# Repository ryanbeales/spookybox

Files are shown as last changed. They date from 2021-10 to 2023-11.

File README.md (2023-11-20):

# What is this?
It's a spooky box version 3! For 2023 it's no longer in a pumpkin, but back in it's box. Version 1 was in a box and that's how it got it's name and we're back to continuing the tradition. You can check out what the 2021 version did [here](https://github.com/ryanbeales/spookybox/tree/spookyboxv1) and 2023 [here](https://github.com/ryanbeales/spookybox/tree/spookyboxv2).

This is some face tracking which is then used as an input to drive some servos that direct some fake plastic eyeballs to follow people around. All this to hopefully spook our Halloween vistors. Success rate so far is about 10% of kids spooked in both 2021 and 2022. 2023 upped this to a better 30%. 2024 really needs to terrify people...

Here's a video of it working (click on the image to play it):
<br>SpookyboxV3 outside (http://www.youtube.com/watch?<br>v=ynq5hFvTToc)<br>

For 2023 it was mostly UI improvementsm so here's a video of the UI:
<br>SpookyboxV3 inside (http://www.youtube.com/watch?v=F0AnC8ocOAw)<br>

The red dot will aim where it finds a face. Posenet is pretty good at finding faces, what is not good is me trying to make a single point out of that. It should be finding the top left corner of the bounding box of the face it finds. It's not quite doing that. But better than nothing! For 2023 i've added some manual controls and some tuning for the lid servo open/close points so we can get that satisfying slap when it closes. There's a manual lid control option which will keep the eyes tracking whatever it finds.

# What's going on here?

Spookyboxv1 used OpenCV running on the Raspberry Pi 3, however, this was way to underpowered for what I was attempting to do. 
Spookyboxv2 offloaded all the face detecting to a desktop or phone browser with an attached GPU or AI accelleration (in a phone) and can find faces/ears/noses/eyes MUCH faster and more accurately with Tensorflow JS and PoseNet.
Spookyboxv3 much the same as v2, but software improvements and back to the box.

Maybe this diagram might help? Maybe it just makes things more confusing.

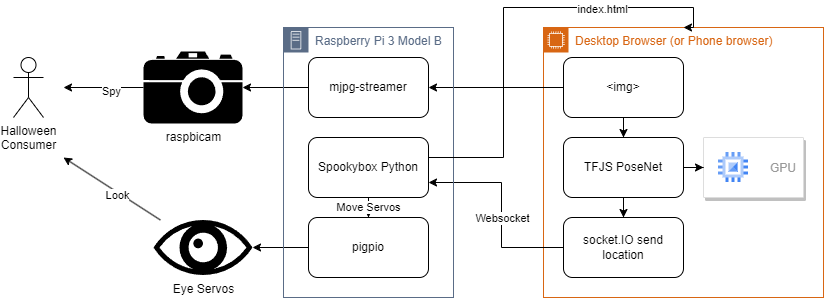
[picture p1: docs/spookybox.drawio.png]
diagram


# Parts needed/used

- Monkmakes Servosix
- 3 Servos
- Bits'o'wire
- Random amazon plastic eyes
- 1 metal rod
- Glue
- 3D print of ./freecad_models/Spookybox2023-2.FCStd (designed to fit everything below)
- 3D print of ./freecad_models/ServoSixCase.FCStd
- 3D print of [Raspberry Pi 3 Model A+ Case](http://www.thingiverse.com/thing:3683365)
- 3D print of [Raspberry pi camera case/enclosure](https://www.thingiverse.com/thing:92208)
- 3D print of [Dasaki Compact Animatronic Eyes](https://www.thingiverse.com/thing:266765)
- A box
- Some small screws for the animatronic eyes
- Raspberry Pi 3 Model A+
- Raspbicam
- SD Card
- Power supply
- Some more powerful hardware to drive it (a semi-recent phone will do, or a Nvidia 4090)

# Assembly photos

A view of the outside:
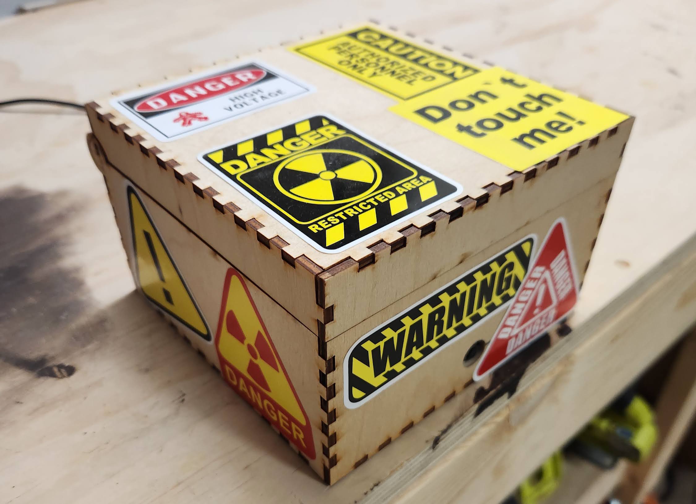
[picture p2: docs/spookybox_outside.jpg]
Outside
</br></br>

And the inside:
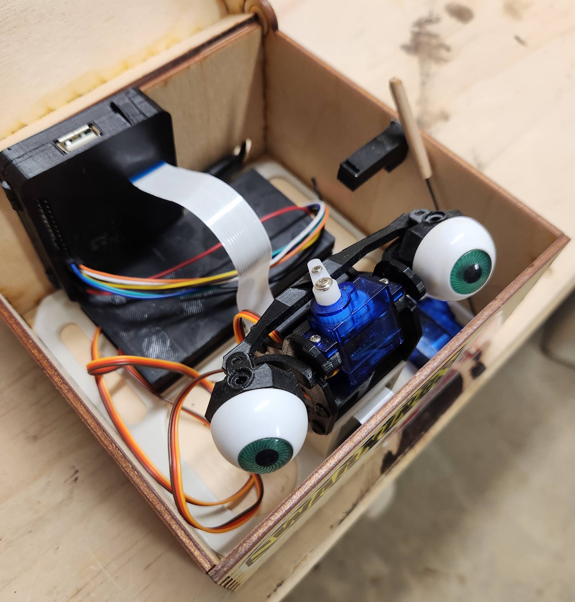
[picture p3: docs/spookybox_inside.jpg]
Inside
</br></br>

The raspbicam has a little hole to peek through the box, harder to see with all the stickers. The lid servo is using a small metal rod with a dowel on the end to make better contact with an old 3D printed part that is glued to the lid.

# Running it
These are my rough notes so I remember what to do for Halloween 2024.

1. Get a raspberry pi and camera module, and servos
1. 3D print all the parts
1. Git clone this in to /home/pi/src/
1. Run install.sh
1. Get spooky.
1. Open a browser on a mobile or desktop device to http://spookyboxpi.local:5000/static/index.html

# TODO

- Increased spookyness (Speakers and some AI voice cloning? Smoke machine?)
- Some sort of CI/CD to pull new changes of the UI down (that's taking my day job home...)
- Add more power. Sometimes the lid servo can consume all the power so the eyes get stuck.

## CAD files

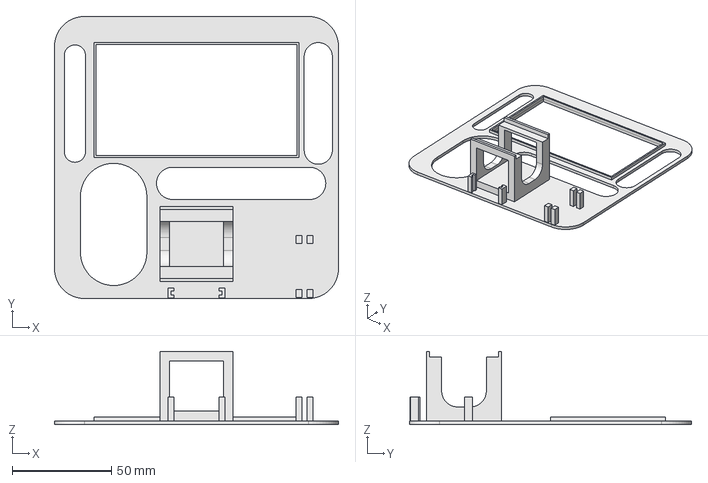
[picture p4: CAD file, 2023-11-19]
freecad_model/SpookyBox2023-2.FCStd
143.0 x 142.0 x 37.0 mm

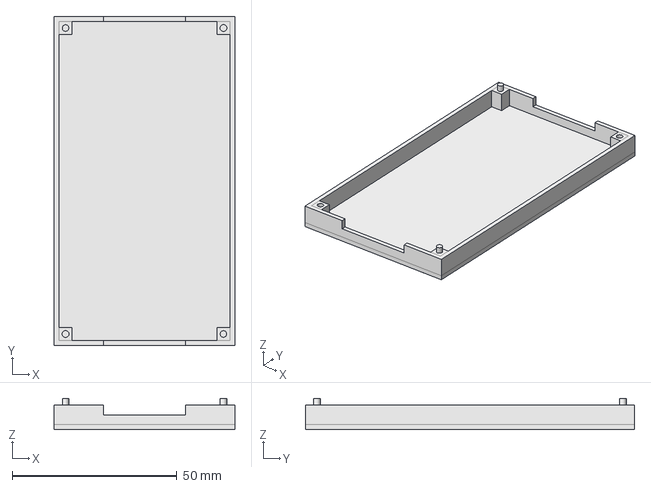
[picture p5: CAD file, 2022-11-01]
freecad_model/ServoSixCase.FCStd
55.0 x 100.0 x 9.50 mm

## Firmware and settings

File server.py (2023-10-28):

from flask import Flask, render_template, current_app
from flask_socketio import SocketIO
from servos import Servo

app = Flask(__name__)
app.config['SECRET_KEY'] = 'spooooooky'
socketio = SocketIO(app)

# Set up our servos, offset by -20 to account for where it was installed
horizontalservo = Servo(23, offset=-20)
verticalservo = Servo(27)
lidservo = Servo(17)

@socketio.on('faceposition')
def handle_message(data):
    #message format is [current x, current y, max x, max y, lidposition].
    current_X = data[0]
    current_Y = data[1]
    lidposition = data[2]

    # Move eyes
    horizontalservo.set_fraction(current_X, minimum=-36, maximum=30)
    verticalservo.set_fraction(current_Y, minimum=-45, maximum=45)
    # Open=-60, closed=20
    lidservo.set_fraction(lidposition, minimum=-60, maximum=20)

if __name__ == '__main__':
    # Bind to all addresses, allow to start via systemd
    socketio.run(app, host='0.0.0.0', allow_unsafe_werkzeug=True)

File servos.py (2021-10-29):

import pigpio
import RPi.GPIO as GPIO

import logging
logger = logging.getLogger(__name__)

import threading, queue

class Servo():
    def __init__(self, pin, min_angle=-90, max_angle=90, offset=0, min_pulse_width=500, max_pulse_width=2500, movement_delay=0.5):
        self.pin = pin
        self.min_angle=min_angle
        self.max_angle=max_angle
        self.min_pulse_width=min_pulse_width
        self.max_pulse_width=max_pulse_width
        self.movement_delay=movement_delay
        self.offset = offset

        # Use pigpio to handle the PWM on the GPIO pin
        self.pwm = pigpio.pi()
        self.pwm.set_mode(pin, pigpio.OUTPUT)
        logger.debug(f"New servo on GPIO pin {self.pin}")
        self.timerthread = None

        logging.debug("Starting servo worker thread")
        # Create a queue to communicate between threads, and start the queue listening thread
        self.q = queue.Queue()
        threading.Thread(target=self.worker, daemon=True, name=f"Servo-{self.pin}-Worker").start()

        
    # Specify a fractional distance instead of an absolute angle
    def set_fraction(self, fraction, minimum=-30, maximum=30):
        angle = minimum + ((maximum - minimum) * fraction)
        self.set_angle(angle)

    # From and input angle, calculate the pulse width to be sent to the servo
    def calculate_pulse_width(self, angle):
        angle_range = float(self.max_angle - self.min_angle)
        fractional = (angle + angle_range/2) / angle_range
        pulse_width = (fractional * (self.max_pulse_width - self.min_pulse_width)) + self.min_pulse_width
        return int(pulse_width)

    # Queue up an angle change for the servo
    def set_angle(self, angle):
        logger.debug(f"set_angle {angle} for servo {self.pin}")
        self.q.put(angle + self.offset)

    # Move Servo to desired angle
    def _set_angle(self, angle):
        # If we have a pending timer thread, cancel it.
        if self.timerthread:
            self.timerthread.cancel()

        # Turn on PWM on servo pin
        self.pwm.set_PWM_frequency(self.pin, 50)
        
        # Cap the min/max angle
        if (angle > self.max_angle):
            angle = self.max_angle
        if (angle < self.min_angle):
            angle = self.min_angle

        # Work out the pulse width based on the angle
        pulsewidth = self.calculate_pulse_width(angle)
        
        logger.debug(f"servo = {self.pin}, angle = {angle}, pulsewidth = {pulsewidth}")
        
        # Set the pulse
        self.pwm.set_servo_pulsewidth(self.pin, pulsewidth)

        # Create a timer thread to turn off the PWM on the pin to prevent jitter
        # PWM is software controlled on the pi, they'll make a lot of idle noise
        # if we don't do this.
        # The delay of 2 seconds is to allow the servo to move to the desired angle.
        self.timerthread = threading.Timer(2, self.turn_off_pwm)
        self.timerthread.start()
        self.timerthread.name = f"Servo-{self.pin}-StopTimer"

    # Turn off PWM for the GPIO pin the servo is connected to, to prevent jitter.
    def turn_off_pwm(self):
        logger.debug(f'Turning off PWM on pin {self.pin}')
        self.pwm.set_PWM_dutycycle(self.pin,0)
        self.pwm.set_PWM_frequency(self.pin,0)
        self.stop_event = None

    # Main thread loop to listen to incoming position requests via the queue.
    def worker(self):
        while True:
            logger.debug('Waiting for queued message')
            try:
                angle = self.q.get(block=True, timeout=10)
                logger.debug(f'Recieved {angle} from queue, setting it')
                self._set_angle(angle)
                logger.debug('Queued task done')
                self.q.task_done()
            except queue.Empty:
                logger.debug('Queue was empty, retrying.')

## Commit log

2021-10-22 Threading and Logging
2021-10-25 Threads on servos as a default
2021-10-25 Thread name update
2021-10-29 Documentation, and angle was set wrong
    [servos.py]
2021-10-29 Save freecad model, remove old flask template.
    [SpookyBox.FCStd]
2021-11-01 Ignore full frame movement, probably vibrations
2022-10-31 Fix for when there are no humans on camera
2022-11-01 2022 Documentation
    [PumpkinEyeMount.FCStd, ServoSixCase.FCStd, SpookyBox.FCStd]
2023-10-28 add licposition servo to python
2023-10-28 make lid servo move
2023-10-28 use a timer to call function
2023-10-28 fix servo limit
2023-10-31 Add a timer to close the lid
2023-10-31 Only clear timer where it is already set.
2023-11-19 Update freecad models
    [PumpkinEyeMount.FCStd, SpookyBox2023-2.FCStd]
